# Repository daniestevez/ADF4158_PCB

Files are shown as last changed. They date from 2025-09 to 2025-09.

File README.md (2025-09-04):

# ADF4158 + HMC391 PCB

This project is a PCB that contains an
[ADF4158](https://www.analog.com/en/products/adf4158.html) direct
modulation/waveform generating fractional-N frequency synthesizer and a
[HMC391](https://www.analog.com/en/products/hmc391.html) 3.9 - 4.45 GHz VCO. The
board is primarily intended as an LO source for a 10 GHz FMCW radar inspired by
the
[ADALM-PHASER](https://wiki.analog.com/resources/eval/user-guides/circuits-from-the-lab/cn0566/overview_setup). The
VCO output can be used with a subharmonic mixer and an IF around 1.6 GHz to
cover the 10 - 10.5 GHz amateur radio band.

The board runs from a 12 - 16 VDC supply, exposes all the control pins of the
ADF4158 in a 2.58 mm pin header (3.3V logic) and includes an optional 10 MHz
reference input. The BOM cost is around 50€.

The PLL loop filter has been designed with
[ADIsimPLL](https://www.analog.com/en/lp/resources/adisimpll.html). The design
file is [ADF4158_HMC391.pll](ADF4158_HMC391.pll).

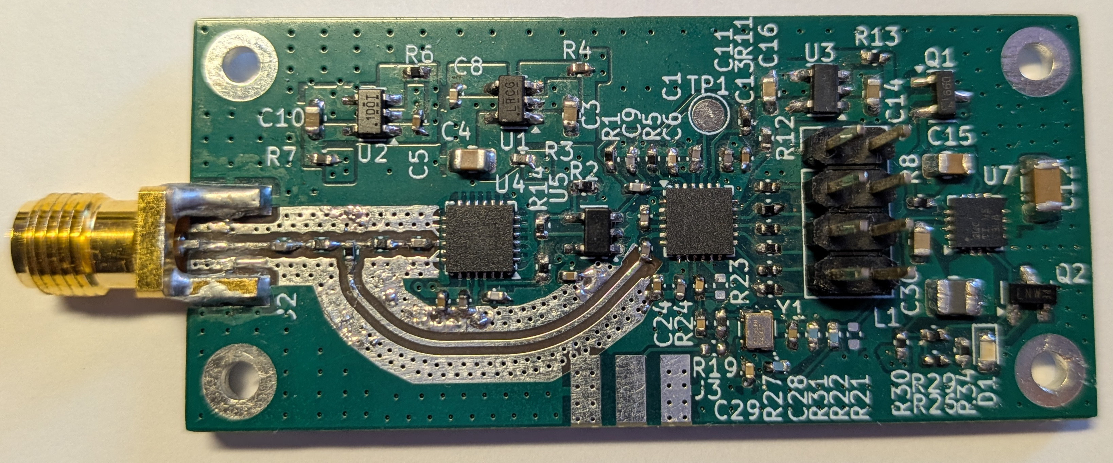
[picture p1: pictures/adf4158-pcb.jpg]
Assembled PCB


PCB top 3D render

## Outputs

Outputs for the latest commit in the `main` branch are built by CI and published
to Github pages. Additionally, outputs for each commit are published as a Github
artifact.

- [Schematic PDF](https://daniestevez.github.io/ADF4158_PCB/schematic.pdf)
- [PCB PDF](https://daniestevez.github.io/ADF4158_PCB/pcb.pdf)
- [Gerbers](https://daniestevez.github.io/ADF4158_PCB/gerbers.zip)
- [ERC report](https://daniestevez.github.io/ADF4158_PCB/erc.rpt)
- [DRC report](https://daniestevez.github.io/ADF4158_PCB/drc.rpt)
- [PCB top 3D render](https://daniestevez.github.io/ADF4158_PCB/pcb-top.png)
- [PCB bottom 3D render](https://daniestevez.github.io/ADF4158_PCB/pcb-bottom.png)

## BOM

The BOM for this project is available as a [DigiKey
list](https://www.digikey.es/en/mylists/list/1BEYR2RWXI). Note that this list
includes DNP components such as the SMA connector for the external 10 MHz
reference. You might want to exclude these components from your purchase.

## PCB fabrication

The PCB is intended to be fabricated on [JLCPCB](https://jlcpcb.com/) using the
following options:

- Base material: FR-4
- Layers: 4
- Deburring/Edge rounding: Yes
- PCB thickness: 1.6 mm
- Material type: FR4-Standard TG 135-140
- Surface finish: HASL (with lead)
- Outer copper weight: 1 oz
- Inner copper weight: 0.5 oz
- Specify stackup: yes
- Layer stackup: JLC04161H-7628 (50 ohm RF traces are designed for this stack up)
- Via covering: plugged
- Min via hole size/diamager: 0.3 mm (0.4/0.45 mm)

These options are very inexpensive: $7.10 for qty. 5, $13.20 for qty. 10.

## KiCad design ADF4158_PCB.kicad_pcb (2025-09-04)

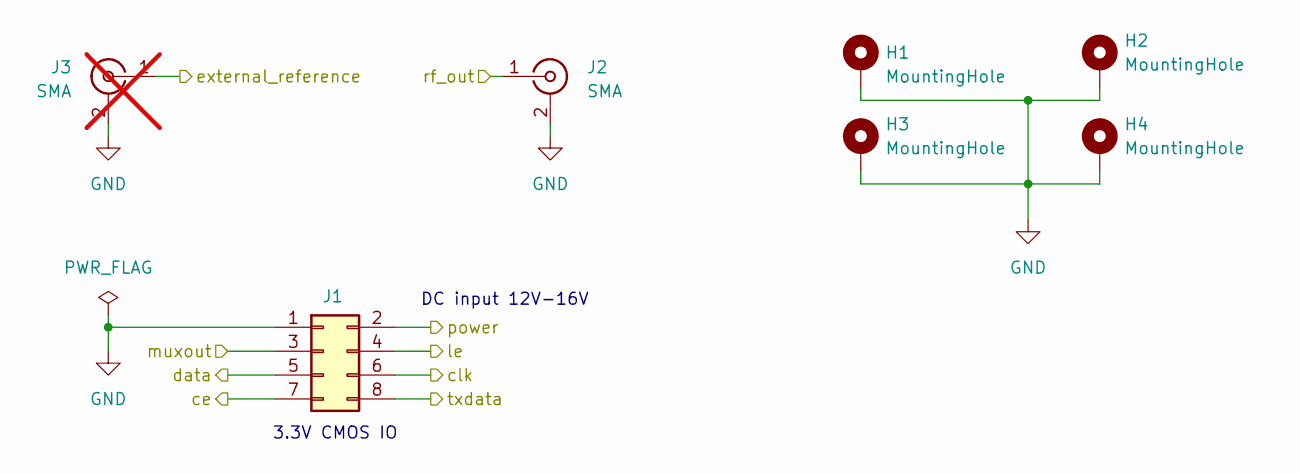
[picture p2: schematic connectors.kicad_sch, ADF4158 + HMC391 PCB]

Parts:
H1, H2, H3, H4: MountingHole; MountingHole_2.2mm_M2_Pad
J1: Conn_02x04_Odd_Even; PinHeader_2x04_P2.54mm_Vertical; Digikey Part Number 2057-PH2-08-UA-ND
J2: SMA; 2484637-1; Digikey Part Number 343-2484637-1-ND
J3: SMA; WRL-23187; Digikey Part Number 1568-WRL-23187-ND; not fitted

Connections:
/ADF4158 + HMC391/ce: J1.7; also elsewhere on the board
/ADF4158 + HMC391/clk: J1.6; also elsewhere on the board
/ADF4158 + HMC391/data: J1.5; also elsewhere on the board
/ADF4158 + HMC391/external_reference: J3.1 (In); also elsewhere on the board
/ADF4158 + HMC391/le: J1.4; also elsewhere on the board
/ADF4158 + HMC391/txdata: J1.8; also elsewhere on the board
/Connectors/power: J1.2; also elsewhere on the board
/muxout: J1.3; also elsewhere on the board
/rf_out: J2.1 (In); also elsewhere on the board
GND: H1.1, H2.1, H3.1, H4.1, J1.1, J2.2 (Ext), J3.2 (Ext); also elsewhere on the board

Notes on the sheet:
DC input 12V-16V
3.3V CMOS IO

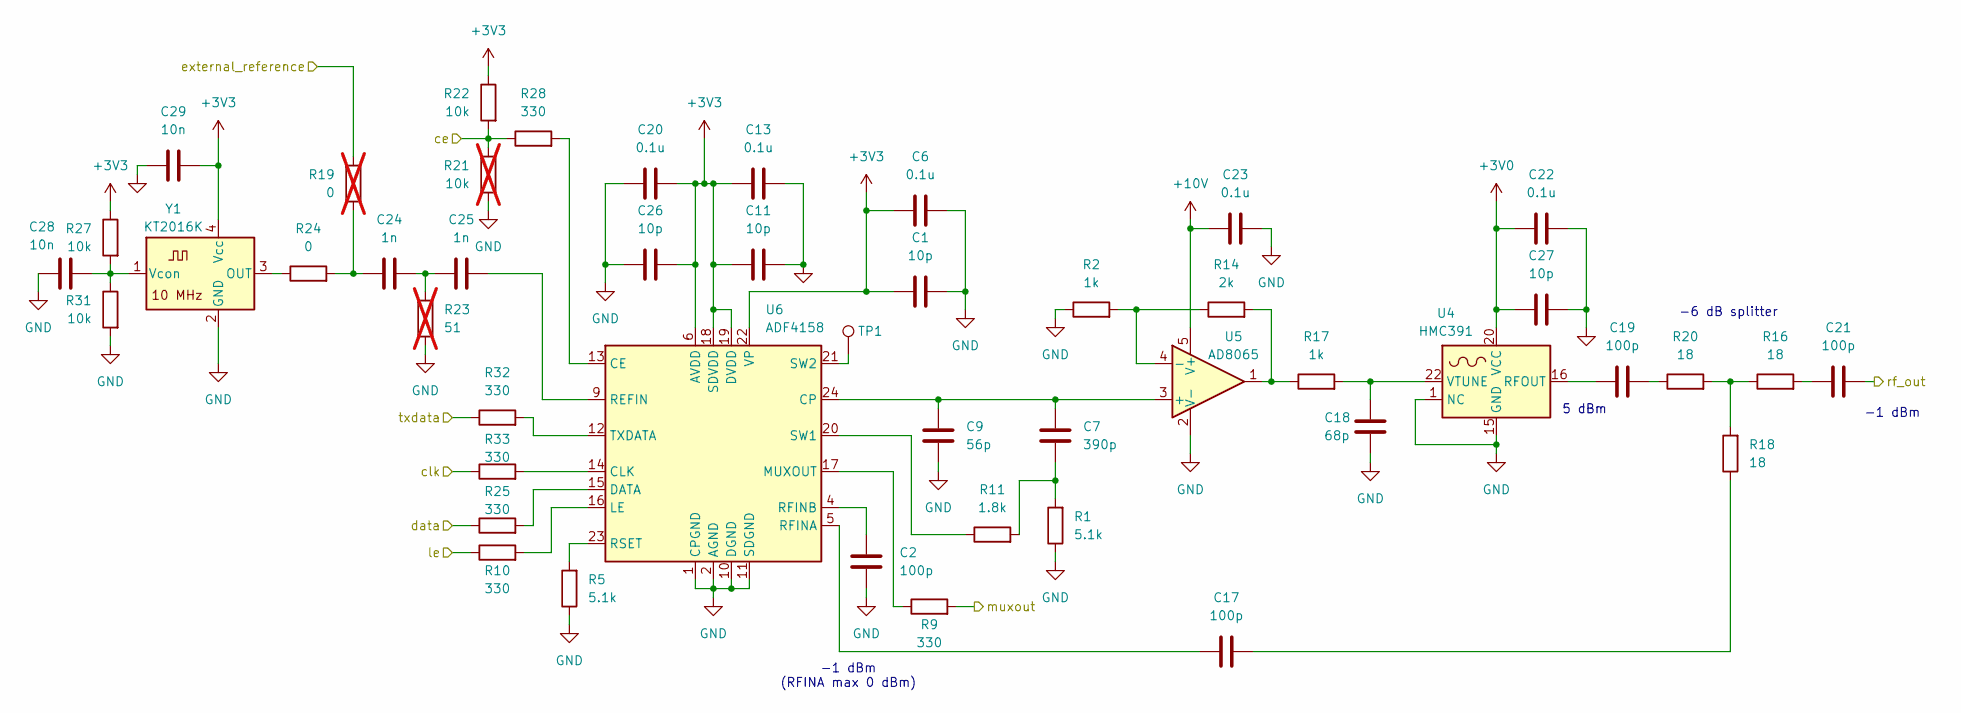
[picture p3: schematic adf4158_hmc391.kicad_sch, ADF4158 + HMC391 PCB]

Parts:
C1, C11, C26, C27: 10p; C_0402_1005Metric; Digikey Part Number 1276-1139-1-ND
C2, C17, C19, C21: 100p; C_0402_1005Metric; Digikey Part Number 1276-1025-1-ND
C6, C13, C20, C22, C23: 0.1u; C_0402_1005Metric; Digikey Part Number 1276-1002-1-ND
C7: 390p; C_0402_1005Metric; Digikey Part Number 490-1296-1-ND
C9: 56p; C_0402_1005Metric; Digikey Part Number 490-1288-1-ND
C18: 68p; C_0402_1005Metric; Digikey Part Number 490-5876-1-ND
C24, C25: 1n; C_0402_1005Metric; Digikey Part Number 1276-1032-1-ND
C28, C29: 10n; C_0402_1005Metric; Digikey Part Number 1276-1028-1-ND
R1, R5: 5.1k; R_0402_1005Metric; Digikey Part Number P5.1KDCCT-ND
R2, R17: 1k; R_0402_1005Metric; Digikey Part Number P1.00KLCT-ND
R9, R10, R25, R28, R32, R33: 330; R_0402_1005Metric; Digikey Part Number P330LCT-ND
R11: 1.8k; R_0402_1005Metric; Digikey Part Number P1.80KLCT-ND
R14: 2k; R_0402_1005Metric; Digikey Part Number P2.00KLCT-ND
R16, R18, R20: 18; R_0402_1005Metric; Digikey Part Number P18.0LCT-ND
R19: 0; R_0402_1005Metric; Digikey Part Number P0.0JCT-ND; not fitted
R21: 10k; R_0402_1005Metric; Digikey Part Number P10.0KLCT-ND; not fitted
R22, R27, R31: 10k; R_0402_1005Metric; Digikey Part Number P10.0KLCT-ND
R23: 51; R_0402_1005Metric; Digikey Part Number P51.0LCT-ND; not fitted
R24: 0; R_0402_1005Metric; Digikey Part Number P0.0JCT-ND
TP1: TestPoint; TestPoint_Pad_D2.0mm
U4: HMC391; QFN-24-1EP_4x4mm_P0.5mm_EP2.8x2.8mm; Digikey Part Number 505-HMC391LP4ECT-ND
U5: AD8065; TSOT-23-5; Digikey Part Number AD8065ARTZ-REELCT-ND
U6: ADF4158; LFCSP-24-1EP_4x4mm_P0.5mm_EP2.5x2.5mm; Digikey Part Number 505-ADF4158CCPZ-ND
Y1: KT2016K; Digikey Part Number 478-KT2016K10000ZAW33ZGKCT-ND

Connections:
+3V0: C22.2, C27.2, U4.20 (VCC); also elsewhere on the board
+3V3: C1.2, C6.2, C11.2, C13.2, C20.2, C26.2, C29.1, R22.1, R27.1, U6.6 (AVDD), U6.7 (AVDD), U6.8 (AVDD), U6.18 (SDVDD), U6.19 (DVDD), U6.22 (VP), Y1.4 (Vcc); also elsewhere on the board
+10V: C23.2, U5.5 (V+); also elsewhere on the board
/ADF4158 + HMC391/ce: R21.1, R22.2, R28.1; also elsewhere on the board
/ADF4158 + HMC391/clk: R33.1; also elsewhere on the board
/ADF4158 + HMC391/data: R25.1; also elsewhere on the board
/ADF4158 + HMC391/external_reference: R19.2; also elsewhere on the board
/ADF4158 + HMC391/le: R10.1; also elsewhere on the board
/ADF4158 + HMC391/txdata: R32.1; also elsewhere on the board
/muxout: R9.2; also elsewhere on the board
/rf_out: C21.2; also elsewhere on the board
GND: C1.1, C2.2, C6.1, C9.2, C11.1, C13.1, C18.2, C20.1, C22.1, C23.1, C26.1, C27.1, C28.1, C29.2, R1.1, R2.1, R5.1, R21.2, R23.1, R31.2, U4.1 (NC), U4.2 (NC), U4.3 (NC), U4.4 (NC), U4.5 (NC), U4.6 (NC), U4.7 (NC), U4.8 (NC), U4.9 (NC), U4.10 (NC), U4.11 (NC), U4.12 (NC), U4.13 (NC), U4.14 (NC), U4.15 (GND), U4.17 (NC), U4.18 (NC), U4.19 (NC), U4.21 (NC), U4.23 (NC), U4.24 (NC), U4.25 (GND), U5.2 (V-), U6.1 (CPGND), U6.2 (AGND), U6.3 (AGND), U6.10 (DGND), U6.11 (SDGND), U6.25 (AGND), Y1.2 (GND); also elsewhere on the board
unnamed: C7.2, R1.2, R11.2
unnamed: C17.2, R18.1
unnamed: C19.2, R20.1
unnamed: C21.1, R16.2
unnamed: C24.1, R19.1, R24.2
unnamed: C24.2, C25.1, R23.2
unnamed: R14.2, R17.1, U5.1
unnamed: R16.1, R18.2, R20.2
unnamed: C19.1, U4.16 (RFOUT)
unnamed: C18.1, R17.2, U4.22 (VTUNE)
unnamed: C7.1, C9.1, U5.3 (+), U6.24 (CP)
unnamed: R2.2, R14.1, U5.4 (-)
unnamed: R28.2, U6.13 (CE)
unnamed: R33.2, U6.14 (CLK)
unnamed: R25.2, U6.15 (DATA)
unnamed: R10.2, U6.16 (LE)
unnamed: R9.1, U6.17 (MUXOUT)
unnamed: C25.2, U6.9 (REFIN)
unnamed: C17.1, U6.5 (RFINA)
unnamed: C2.1, U6.4 (RFINB)
unnamed: R5.2, U6.23 (RSET)
unnamed: R11.1, U6.20 (SW1)
unnamed: TP1.1, U6.21 (SW2)
unnamed: R32.2, U6.12 (TXDATA)
unnamed: R24.1, Y1.3 (OUT)
unnamed: C28.2, R27.2, R31.1, Y1.1 (Vcon)

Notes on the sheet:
-6 dB splitter
-1 dBm (RFINA max 0 dBm)
-1 dBm
5 dBm

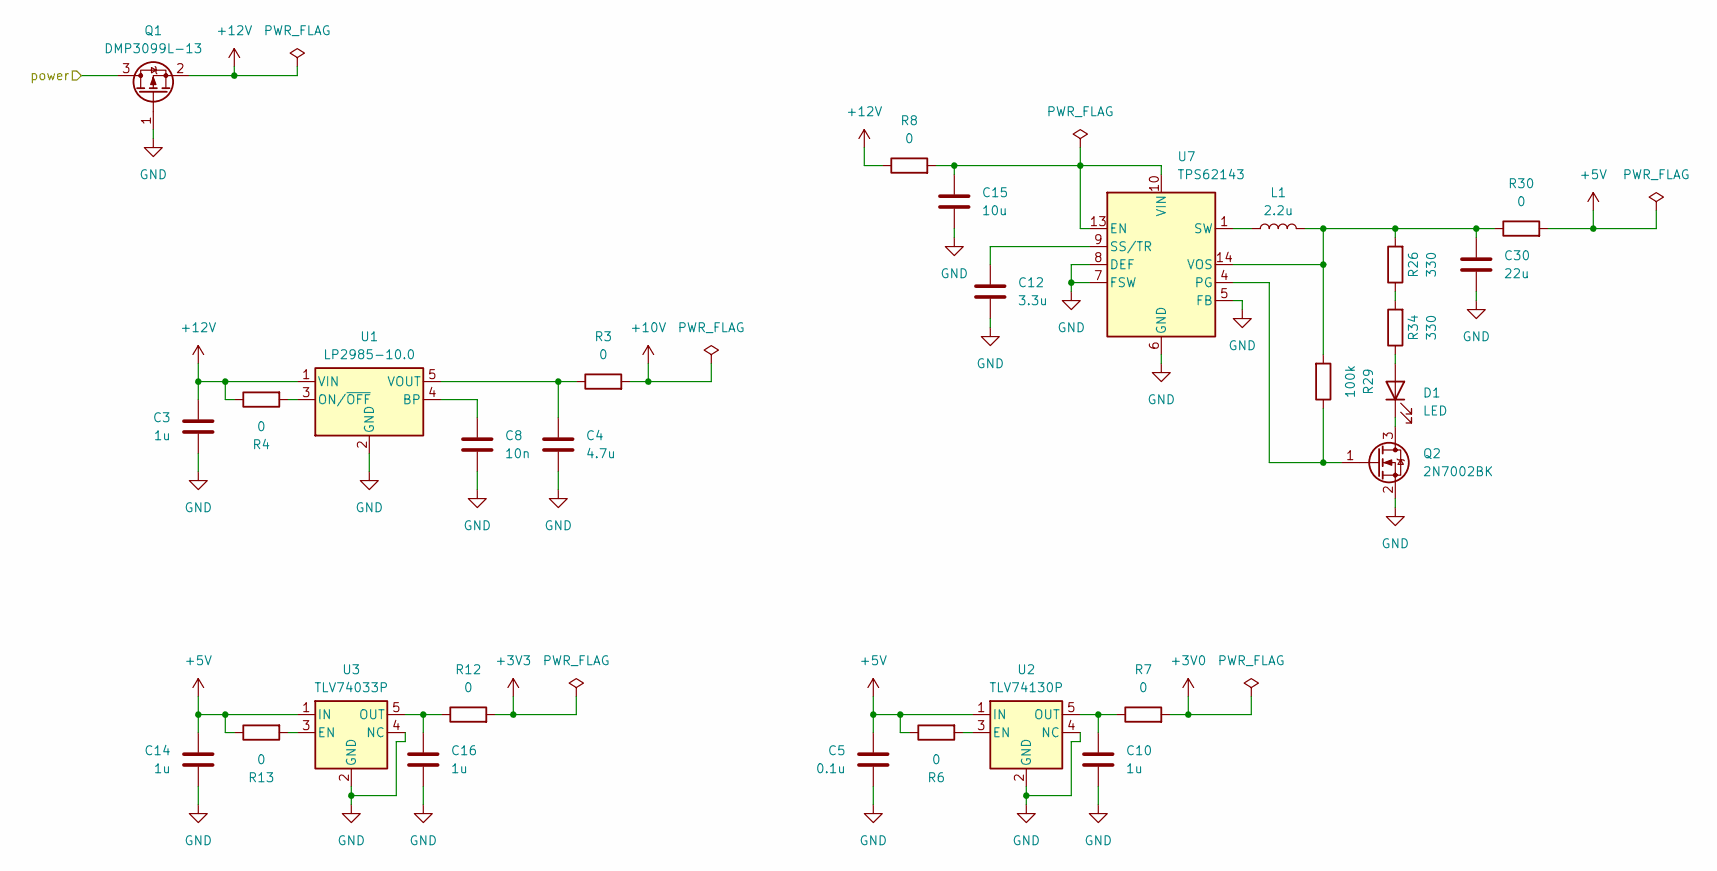
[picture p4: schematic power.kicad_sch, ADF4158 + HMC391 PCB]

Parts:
C3, C10, C14, C16: 1u; C_0603_1608Metric; Digikey Part Number 1276-1184-1-ND
C4: 4.7u; C_0805_2012Metric; Digikey Part Number 490-GRM21BR71C475ME51KCT-ND
C5: 0.1u; C_0402_1005Metric; Digikey Part Number 1276-1002-1-ND
C8: 10n; C_0402_1005Metric; Digikey Part Number 1276-1028-1-ND
C12: 3.3u; C_1206_3216Metric; Digikey Part Number 1276-1841-1-ND
C15: 10u; C_0805_2012Metric; Digikey Part Number 1276-2872-1-ND
C30: 22u; C_0603_1608Metric; Digikey Part Number 1276-1274-1-ND
D1: LED; LED_0603_1608Metric; Digikey Part Number 3147-B1931NG--20D001114U1930CT-ND
L1: 2.2u; L_1008_2520Metric; Digikey Part Number 490-10649-1-ND
Q1: DMP3099L-13; SOT-23-3; Digikey Part Number DMP3099L-13DICT-ND
Q2: 2N7002BK; SOT-23; Digikey Part Number 1727-4789-1-ND
R3, R4, R6, R7, R8, R12, R13, R30: 0; R_0402_1005Metric; Digikey Part Number P0.0JCT-ND
R26, R34: 330; R_0402_1005Metric; Digikey Part Number P330LCT-ND
R29: 100k; R_0402_1005Metric; Digikey Part Number P100KLCT-ND
U1: LP2985-10.0; SOT-23-5; Digikey Part Number 296-24263-1-ND
U2: TLV74130P; SOT-23-5; Digikey Part Number 296-50000-1-ND
U3: TLV74033P; SOT-23-5; Digikey Part Number 296-TLV74033PDBVRCT-ND
U7: TPS62143; VQFN-16-1EP_3x3mm_P0.5mm_EP1.68x1.68mm; Digikey Part Number 296-39448-1-ND

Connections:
+3V0: R7.2; also elsewhere on the board
+3V3: R12.2; also elsewhere on the board
+5V: C5.1, C14.1, R6.1, R13.1, R30.2, U2.1 (IN), U3.1 (IN)
+10V: R3.2; also elsewhere on the board
+12V: C3.1, Q1.2 (S), R4.1, R8.1, U1.1 (VIN)
/Connectors/power: Q1.3 (D); also elsewhere on the board
GND: C3.2, C4.2, C5.2, C8.2, C10.2, C12.2, C14.2, C15.2, C16.2, C30.2, Q1.1 (G), Q2.2 (S), U1.2 (GND), U2.2 (GND), U2.4 (NC), U3.2 (GND), U3.4 (NC), U7.5 (FB), U7.6 (GND), U7.7 (FSW), U7.8 (DEF), U7.15 (GND), U7.16 (GND), U7.17 (GND); also elsewhere on the board
unnamed: D1.2 (A), R34.1
unnamed: D1.1 (K), Q2.3 (D)
unnamed: L1.1, U7.1 (SW), U7.2 (SW), U7.3 (SW)
unnamed: Q2.1 (G), R29.1, U7.4 (PG)
unnamed: R26.1, R34.2
unnamed: C8.1, U1.4 (BP)
unnamed: R4.2, U1.3 (ON/~OFF)
unnamed: C4.1, R3.1, U1.5 (VOUT)
unnamed: R6.2, U2.3 (EN)
unnamed: C10.1, R7.1, U2.5 (OUT)
unnamed: R13.2, U3.3 (EN)
unnamed: C16.1, R12.1, U3.5 (OUT)
unnamed: C15.1, R8.2, U7.10 (VIN), U7.11 (VIN), U7.12 (VIN), U7.13 (EN)
unnamed: C12.1, U7.9 (SS/TR)
unnamed: C30.1, L1.2, R26.2, R29.2, R30.1, U7.14 (VOS)

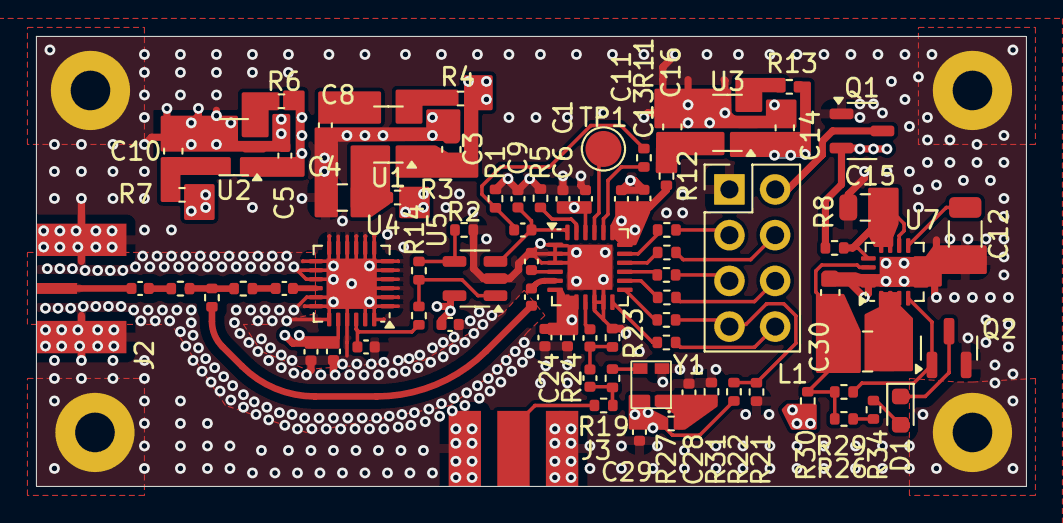
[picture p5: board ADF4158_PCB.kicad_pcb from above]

Board: 4 copper layers, 55.0 x 25.0 mm, 83 parts (0 on the bottom side), 56 nets.

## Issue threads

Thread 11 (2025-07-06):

SMA connector footprints are wrong

daniestevez, 2025-07-06:
When building the board I have realized that the footprint for the RF out connector is wrong. Its ground tabs are too close together for most SMA connectors, including the [TE Connectivity 2484637-1](https://www.digikey.es/es/products/detail/te-connectivity-linx/2484637-1/24771200) in the BOM, and the [Würth 60312202114512](https://www.digikey.es/es/products/detail/w%C3%BCrth-elektronik/60312202114512/10106997) which I ended up buying because the TE Connectivity connector was out of stock (and I don't know why I bought it, because it's for a 1.2 mm PCB).

I have now bought a [Würth 60312202114513](https://www.digikey.es/en/products/detail/w%C3%BCrth-elektronik/60312202114513/10106998), which while not ideal, should fit the footprint reasonably.

The 10 MHz external reference connector has the same problem.

For the next version of the board, the SMA footprints needs to be redesigned carefully, and intended connector must be in the BOM and double checked.

daniestevez, 2025-07-13:
The [Würth 60312202114513](https://www.digikey.es/en/products/detail/w%C3%BCrth-elektronik/60312202114513/10106998) has turned out to be a very good fit for the footprint, so maybe the simplest fix is to amend the BOM to use this connector.

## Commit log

2025-04-20 some minor PCB improvements
    - Do not route 3V0 trace on back right below HMC391 RF out
    - Add multiple vias for 5V and 12V power traces
    [ADF4158_PCB.kicad_pcb]
2025-04-20 switch to 4-layer 1.6mm PCB stackup from JLCPCB
    - By recommendation of reviewers, use a 4-layer 1.6 PCB stackup from
    JLCPCB that gives 0.6 mm 50 ohm CPWG traces on the top layer.
    - Use an SMA connector with a thin pin for the RF output.
    - Remove 51 ohm resistor loading the ADF4518 PCB. This is believed
    to be a mistake in the evaluation board schematic.
    - Add M2 mounting holes to the board corners.
    - Connect NC pins of HMC391 to GND as in the evaluation board.
    [ADF4158_PCB.kicad_pcb, adf4158_hmc391.kicad_sch, connectors.kicad_sch]
2025-04-20 switch from JLC04161H-2116D to JLC04161H-7628 stackup
    Unfortunately the 2116D stackup that I used to get 50 ohm traces
    of approximately 0.6 mm now costs a huge amount. Use instead the
    7628 stackup, which is JLCPCB's cheap/default/recommended stackup.
    This gives 0.3658 mm 50 ohm traces, which is not ideal for matching
    with 0402 parts.
    [ADF4158_PCB.kicad_pcb]
2025-04-20 use thermal relief in GND pour
    - Use thermal relief in GND pour
    - Add vias to SMD GND pads
    [ADF4158_PCB.kicad_pcb]
2025-04-22 add plating to mounting holes
    [ADF4158_PCB.kicad_pcb, connectors.kicad_sch]
2025-04-22 replace U7 footprint vias by manually placed vias
    The thermal vias in the footprint were being connected
    to the groundplane with thermal reliefs and giving other
    troubles (wrong drill size). This replaces them by manually
    placed vias.
    [ADF4158_PCB.kicad_pcb, power.kicad_sch]
2025-04-25 add release dates to schematic and PCB
    [ADF4158_PCB.kicad_pcb, ADF4158_PCB.kicad_sch, adf4158_hmc391.kicad_sch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]
2025-09-04 update footprints from library
    Update footprints from library to fix DRC warnings, since the library
    has now been updated.
    [ADF4158_PCB.kicad_pcb]
2025-09-04 add assembled PCB photo
